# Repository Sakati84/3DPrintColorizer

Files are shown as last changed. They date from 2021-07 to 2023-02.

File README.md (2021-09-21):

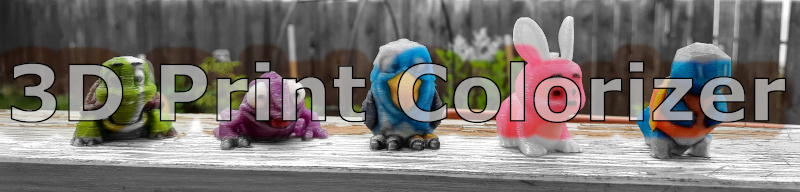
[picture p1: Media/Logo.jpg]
  

**3D Print Colorizer** is a combination of 3D printed parts and a [Cura](https://ultimaker.com/de/software/ultimaker-cura) plugin which allows anyone with an Ender 3 or BLTouch-compatible printer (no CoreXY for now) to produce multi colored models. Have a look at some results:

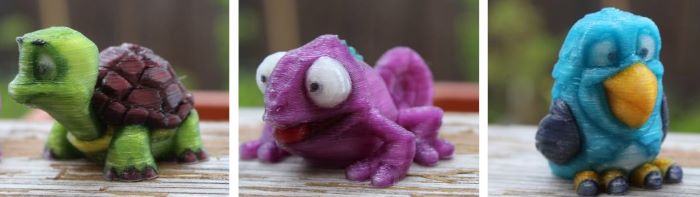
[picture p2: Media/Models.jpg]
  

## Release Notes
- **2021-08-06** Fixed issue with some T-Commands still being in the G-Code as reported by Teaching Tech.
- **2021-08-05** Added big compatibility update. Added parts to mount to nearly any BLTouch-compatible Printer (no CoreXY for now).

## How it works
3D Print Colorizer uses Sharpie or Sharpie-like permanent markers to directly paint on the layers of a 3D print. After a layer is finished printing normally a pen holder, which is mounted to the print head, is used to fetch pens from a special pen rack mounted to the top part of the printer. Normal printing and painting is used alternately to produce a final colored model.

To coordinate the process a special [Cura](https://ultimaker.com/de/software/ultimaker-cura) plugin is used to  add the painting G-Code. After installing the plugin you need to enter some calibration values and afterwards models sliced for an Multi Extrusion printer can be printed on an Ender 3 with full color support.

  
*[YouTube link](https://youtu.be/2vPkmsyEDaQ)*

## Installation
You can watch this video for a quick overview of the setup process:  
IMAGE ALT TEXT HERE (https://www.youtube.com/watch?v=U__G75EYIEQ)  
*[YouTube link](https://youtu.be/2vPkmsyEDaQ)*

Detailed installation instruction are given in the [Wiki](https://github.com/Sakati84/3DPrintColorizer/wiki/1-Hardware-Setup). Please follow each step to complete the installation and get ready for mutli color printing.

> **PLEASE don´t forget to:**  
> + Use **transparent** filament. **No white** filament!
> + Tune your Z-Axis.
> + Use the provided Cura profile as a starting point and **don´t** increase the speeds before you know what you are doing. 

[1. Hardware Setup](https://github.com/Sakati84/3DPrintColorizer/wiki/1-Hardware-Setup)

[2. Materials needed](https://github.com/Sakati84/3DPrintColorizer/wiki/2-Materials)

[3. Calibration](https://github.com/Sakati84/3DPrintColorizer/wiki/3-Calibration)

[4. Software Setup](https://github.com/Sakati84/3DPrintColorizer/wiki/4-Software-Setup)

[5. Printing](https://github.com/Sakati84/3DPrintColorizer/wiki/5-Printing)

---
If you want you can:

<a href="https://www.buymeacoffee.com/sakati" target="_blank">Buy Me A Coffee</a>

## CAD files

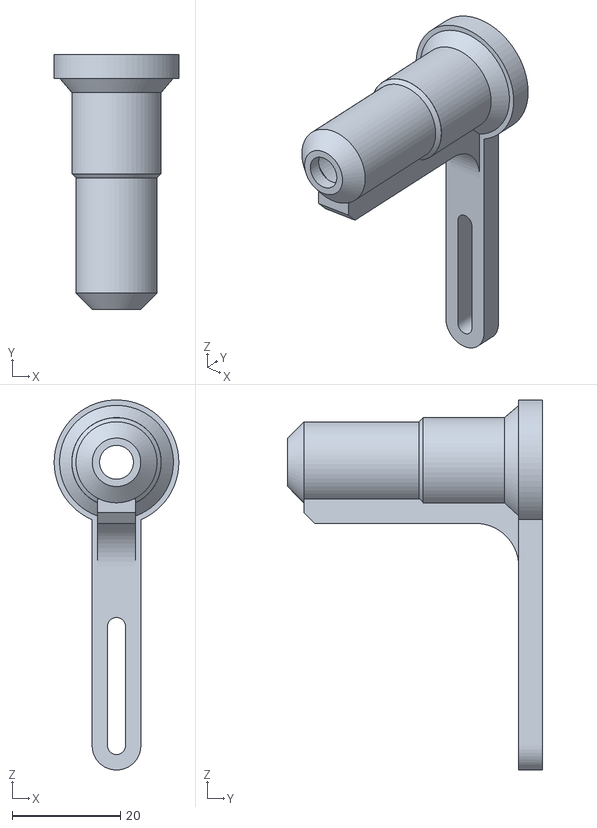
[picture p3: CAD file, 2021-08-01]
Hardware/BLTouchPenHolder/PenHolder_Long+1.stl
23.0 x 47.0 x 68.2

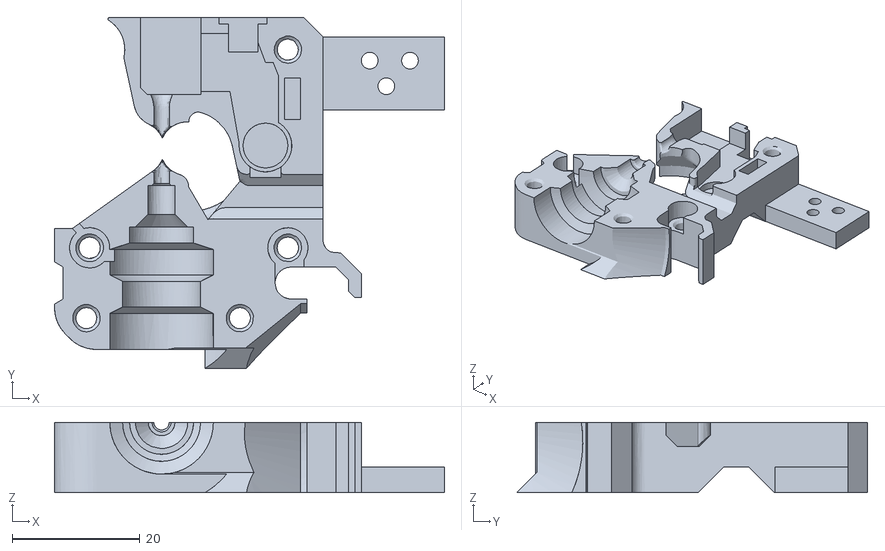
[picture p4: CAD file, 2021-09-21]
Hardware/PrusaMK3S/colorizer-extruder-attachment.stl
61.0 x 54.9 x 11.0

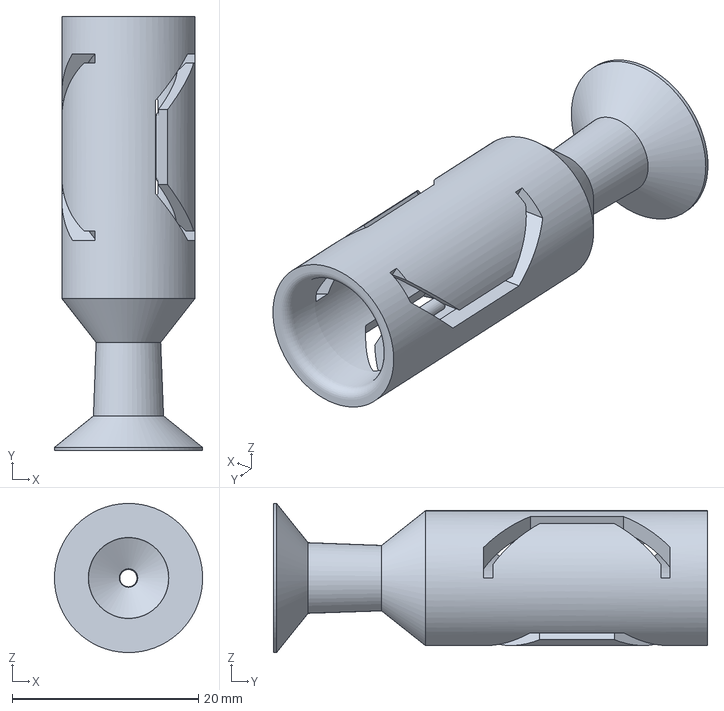
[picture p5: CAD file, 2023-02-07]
Hardware/UFSharpieCap.3mf
15.9 x 46.6 x 16.0 mm

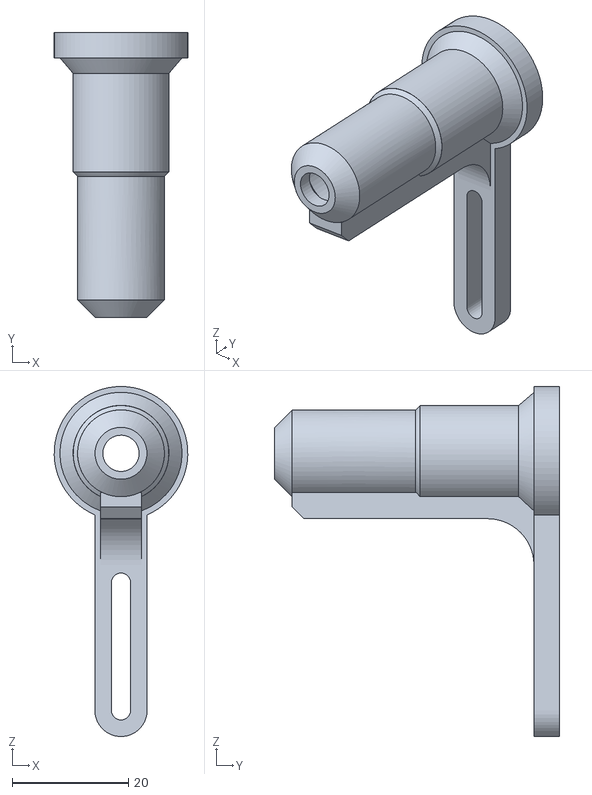
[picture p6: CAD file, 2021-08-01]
Hardware/BLTouchPenHolder/PenHolder_Short+3.stl
23.0 x 49.0 x 60.2

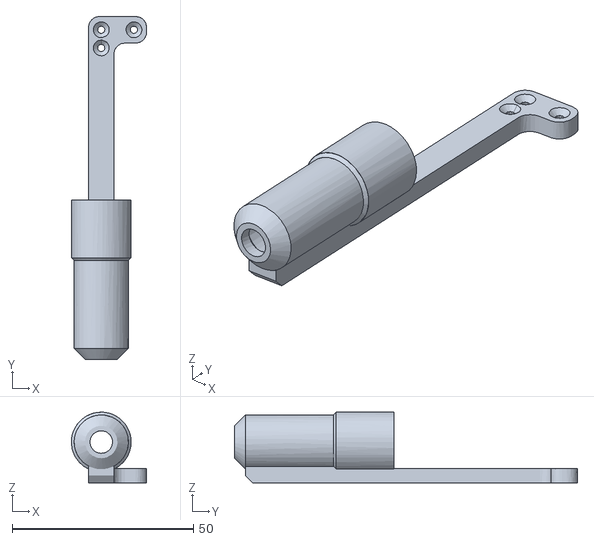
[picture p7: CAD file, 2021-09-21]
Hardware/PrusaMK3S/Colorizer MK3S holder.stl
20.7 x 94.5 x 19.5

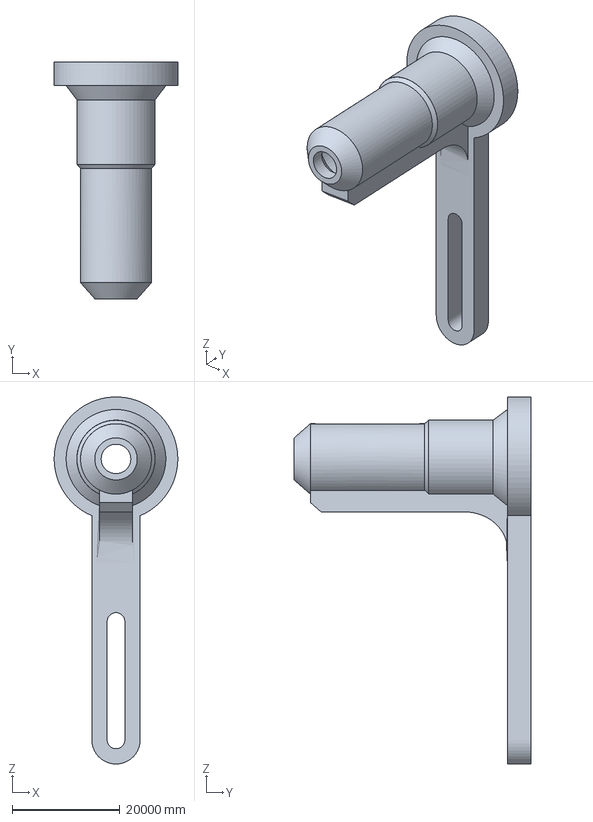
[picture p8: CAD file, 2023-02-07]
Hardware/UFSharpieHolderLong-2.3mf
22997.4 x 44000.0 x 68224.1 mm

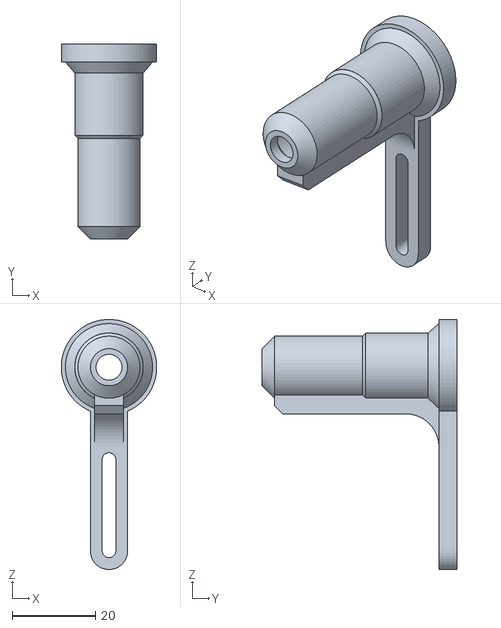
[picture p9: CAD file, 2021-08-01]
Hardware/BLTouchPenHolder/PenHolder_Short+1.stl
23.0 x 47.0 x 60.2

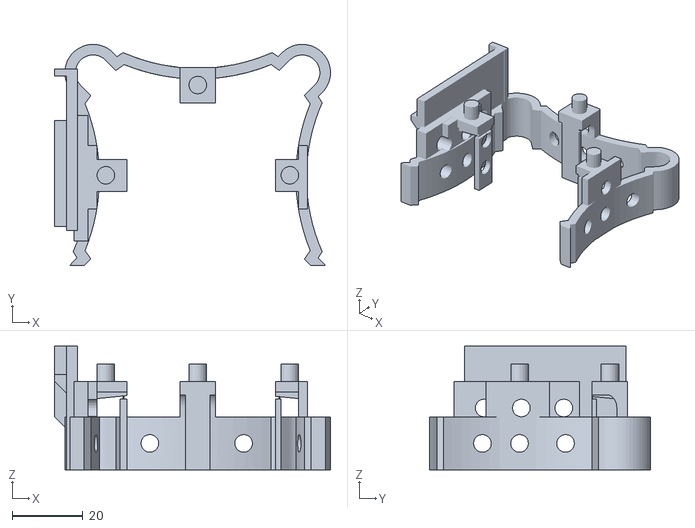
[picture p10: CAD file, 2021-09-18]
Hardware/PenHolder Ender3v2_Cyrus_Sanii (ClipOn).stl
78.0 x 62.5 x 35.0

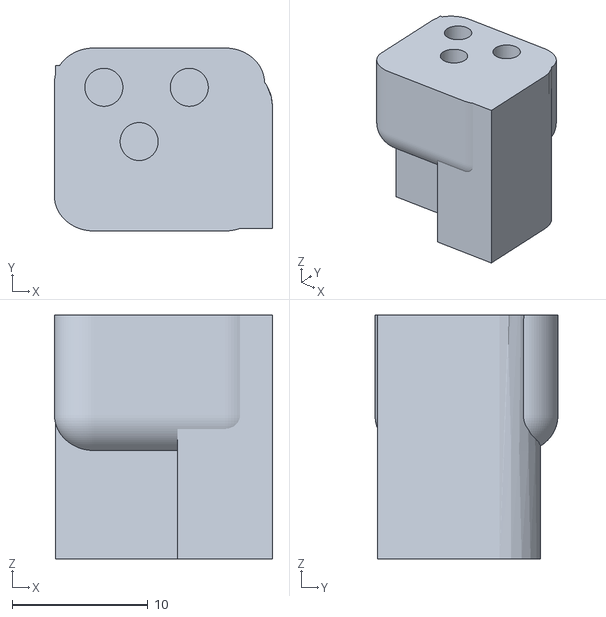
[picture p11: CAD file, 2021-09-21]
Hardware/PrusaMK3S/colorizer-extender.stl
16.1 x 13.5 x 18.0

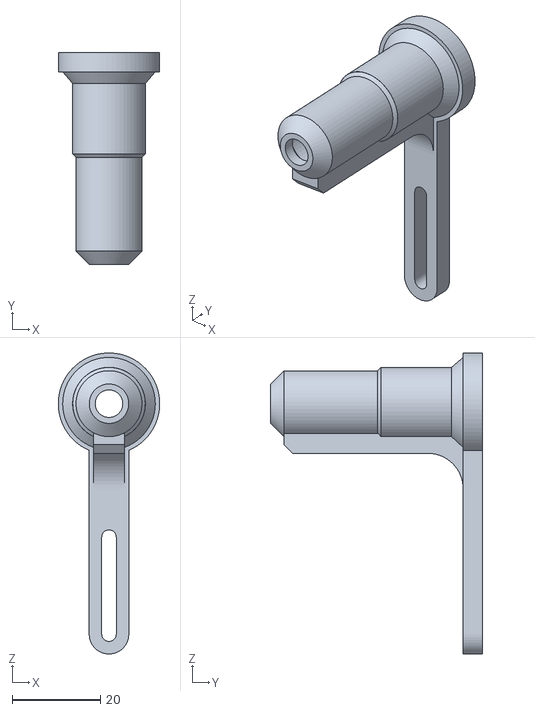
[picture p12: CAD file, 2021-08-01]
Hardware/BLTouchPenHolder/PenHolder_Long+2.stl
23.0 x 48.0 x 68.2

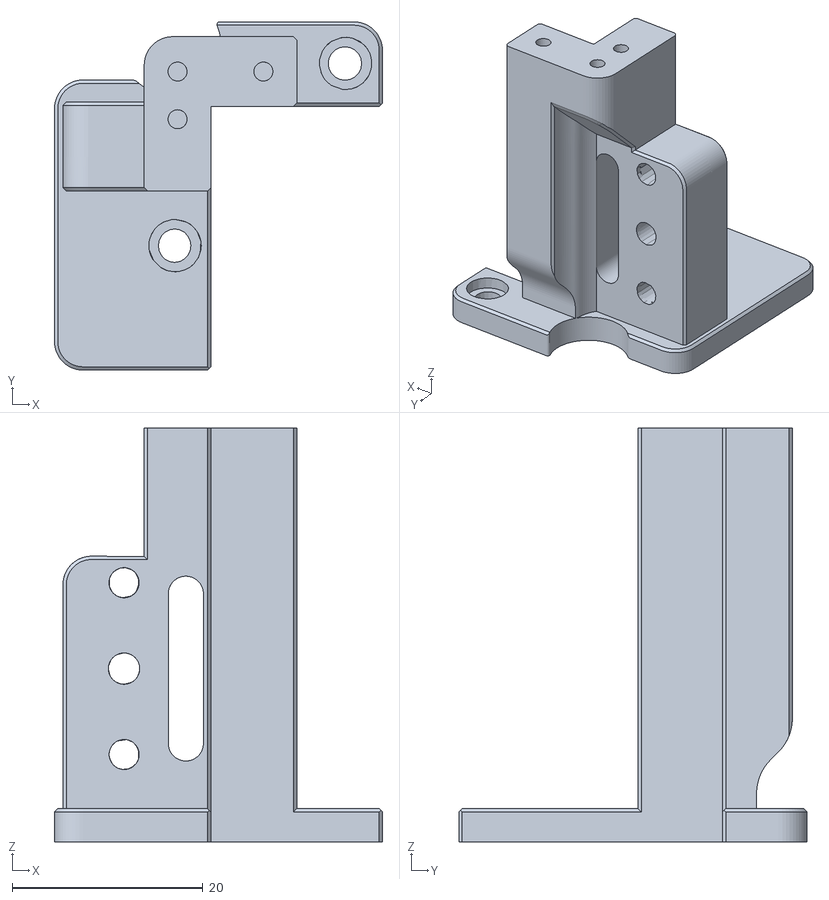
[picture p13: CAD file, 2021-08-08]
Hardware/PenHolderArm_Ender3v1_IntegratedBLTouch.stl
34.4 x 36.5 x 43.4

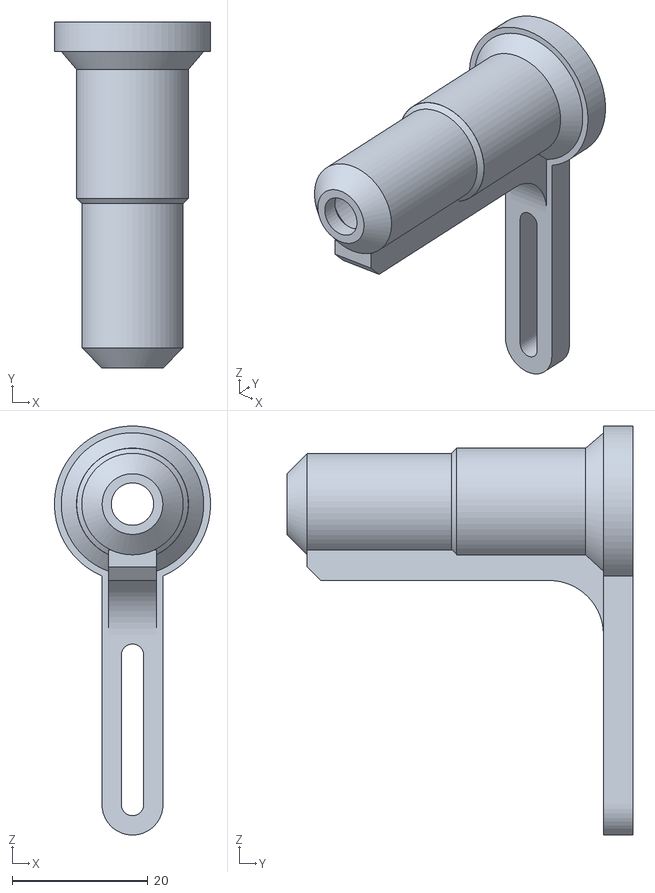
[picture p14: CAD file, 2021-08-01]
Hardware/BLTouchPenHolder/PenHolder_Short+5.stl
23.0 x 51.0 x 60.2

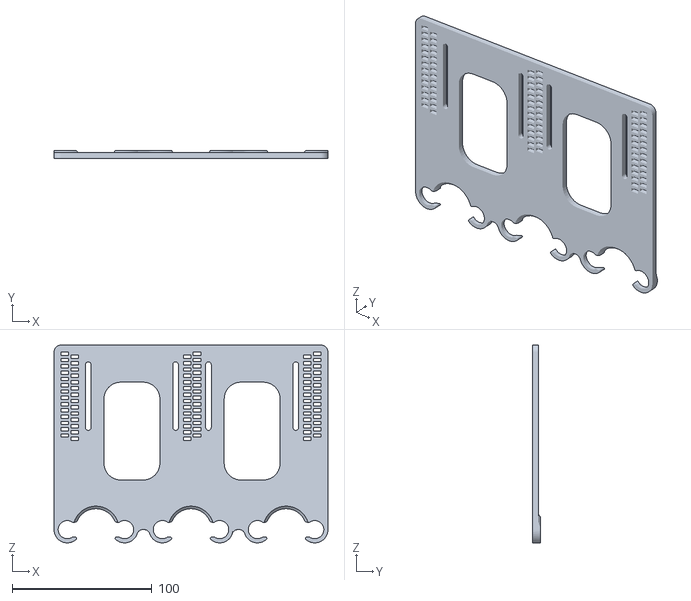
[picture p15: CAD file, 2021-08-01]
Hardware/PenRack_x6.stl
196.0 x 5.40 x 141.5

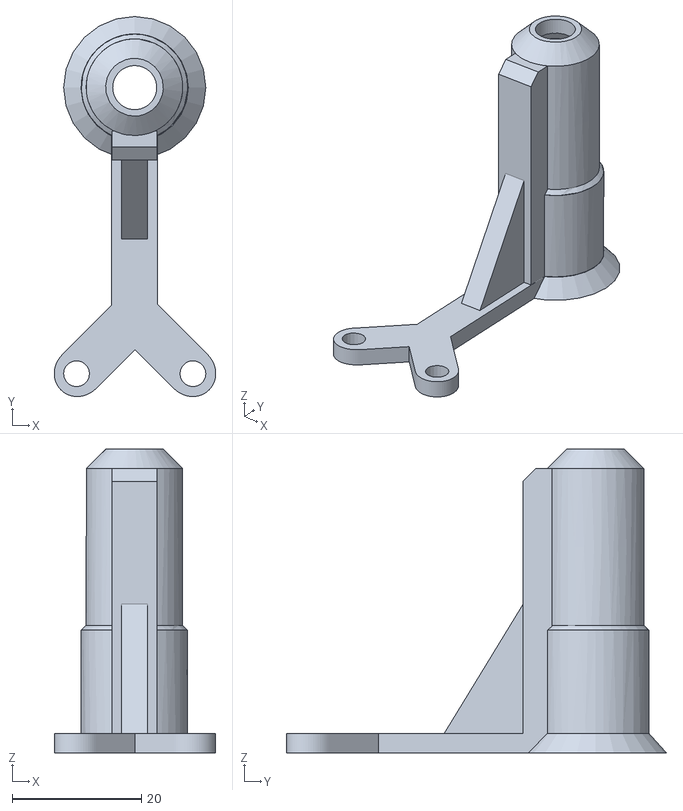
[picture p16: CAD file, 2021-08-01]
Hardware/BLTouchPenHolder/PenHolder_BLTouch_horizontalByZippitybamba.stl
25.0 x 58.8 x 47.0

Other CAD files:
Hardware/PenHolderArm_Ender3v2_byMolesza.stl
Hardware/BLTouchPenHolder/PenHolder_Long+4.stl
Hardware/PenHolder_Sharpie.stl
Hardware/BLTouchPenHolder/PenHolder_Long+3.stl
Hardware/BLTouchPenHolder/PenHolder_Long+5.stl
Hardware/BLTouchPenHolder/PenHolder_Long-1.stl
Hardware/BLTouchPenHolder/PenHolder_Long-2.stl
Hardware/BLTouchPenHolder/PenHolder_Long-3.stl
Hardware/BLTouchPenHolder/PenHolder_Long.stl
Hardware/BLTouchPenHolder/PenHolder_Short+2.stl
Hardware/BLTouchPenHolder/PenHolder_Short+4.stl
Hardware/BLTouchPenHolder/PenHolder_Short-1.stl
Hardware/BLTouchPenHolder/PenHolder_Short-2.stl
Hardware/BLTouchPenHolder/PenHolder_Short-3.stl
Hardware/BLTouchPenHolder/PenHolder_Short.stl
Hardware/PenCap.stl
Hardware/PenHolderArm_Ender3v1.stl
Hardware/PenHolder_Amazon_ShuttleArt(_Sharpie).stl

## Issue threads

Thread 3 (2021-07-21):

No support for G2/G3 codes.

FlyMyPG, 2021-07-21:
I use ArcWelder, which detects arcs made from a sequence of G0/G1 codes and converts the entire sequence to a single G2/G3 code.  It makes highly-detailed STLs print faster and better, especially on 8-bit controllers.

I'm planning to adapt the project to the Sidewinder X1 v4, so I may code this myself if you don't beat me to it!

FlyMyPG, 2021-07-21:
Doh!  I could just ensure ArcWelder runs **_after_** PenColorizer.

Please close this issue if you agree.

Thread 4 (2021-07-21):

Feature request: support

jmding8, 2021-07-21:
Would it be possible to extend the plugin to support using the Sharpie as a release agent for support structures?

Check out this video, which shows how you can use Sharpie as a release agent to enable printing over 100% density support structures with zero Z-gap, and still have the support structure break away from the part easily.
https://www.youtube.com/watch?v=lcOcetpHhTU&ab_channel=ChristianGalles

I've tried it with PLA and ABS and it works amazingly well. The one major downside is either needing to apply the Sharpie manually, or being stuck using a non-zero Z-gap, since none of the open slicer engines support zero-thickness layers. Your system would be perfect for an application like this!

Sakati84, 2021-07-22:
Very first test print
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

jmding8, 2021-07-22:
amazing!

Sakati84, 2021-07-26:
Some other results. This print has no gap between the print and the support interface and was easy to remove.

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

jmding8, 2021-07-26:
looks like the automated system works really well! This is all using the current plugin code? Next step: get this in the hands of a prominent influencer to popularize the technique and the use of the plugin?

Sakati84, 2021-07-26:
@jmding8 i tried to pitch it to makers muse and make anything some weeks ago but got no reply.

Sakati84, 2021-07-26:
@jmding8 the Support Mode isn‘t on GitHub yet. I want to change some stuff before I upload it

ssilverm, 2021-07-27:
Going to be printing this and showing it off at Maker Faire Orlando!

Sakati84, 2021-07-27:
@ssilverm thats really cool. Would be nice if you could post some pictures.

jmding8, 2021-07-27:
I'll poke Tom and Stefan, I'm sure one of them will jump on it

Sakati84, 2021-07-27:
I made a [branch](https://github.com/Sakati84/3DPrintColorizer/tree/supportRelease )for this feature. It´s still very much WIP. I only tested it for supporting horizontal overhangs right now. In the branch you have an updated plugin. In the settings panel you can switch the mode to "support removal". I also suggest you use the new support removal profile a uploaded to the software folder. The new TestModels folder contains my test model from before. If you want to do your own profile you should increase the wall & top speed to a normal/fast level (normally they should be reduced for the colorization profile).

dr3y, 2021-08-16:
but what if i want to print support and also a multicolor model at the same time?

Great addon idea btw

Sakati84, 2021-08-16:
I don't think this would work very well. One would probably destroy parts of the model when removing the support because of the reduced layer adhesion in the Colorado parts

dr3y, 2021-08-16:
well currently i am using a colored model with uncolored supports and it is extremely hard to remove them. i think this would at least make my life easier if the supports were colored also and therefore had a weaker layer adhesion, just like the model. Combined with other support weakening options like decreased flow rate and fill density i could actually print colored protein models quite well :)

Sparrowhawk120, 2021-08-19:
I am trying to use the support removal branch of the repo and I made one or two modifications to the profile but when I try the test model the underside surface ends up looking like this:
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

I watched it while printing and the layer above the support interface didn't stick at all to the sharpie layer while going down (which is what we want of course but not while it's printing!). So I ended up with a bunch of balled up filament on that layer, resulting in the bad underside finish. Since yours clearly worked out @Sakati84 is there anything I did wrong?

Sparrowhawk120, 2021-08-19:
Also, I noticed that there is a z-axis hop every time it moves over the support material even though z-hop is disabled in cura..

jmding8, 2021-08-19:
Guessing that your profile isn't optimized for fully dense supports?
support z distance = 0.0mm
enable support interface = true
support interface density = 90% to 100%

If that doesn't fix it, use the plugin referenced in this conversation to export your settings. Paste them here, and I can take a look

Sparrowhawk120, 2021-08-19:
@jmding8 I do have those settings, yes. 0.0mm, 100% concentric roof interface. I don't see the plugin referenced in this conversation could you tell me what it is?

jmding8, 2021-08-19:
Apologies, I meant to paste this link, but I guess I forgot

https://community.ultimaker.com/topic/35866-include-cura-settings-as-comment-in-gcode-file/

Sparrowhawk120, 2021-08-19:
https://pastebin.com/qMk07FxQ

Here's a pastebin, is this what you were looking for?

Sakati84, 2021-08-19:
>
>
> Also, I noticed that there is a z-axis hop every time it moves over the support material even though z-hop is disabled in cura..

That is one of the WIP things in this branch ;-)

Sakati84, 2021-08-19:
Can you post your g-code? What modifications did you make?

Sparrowhawk120, 2021-08-19:
[SupportTest1.zip](https://github.com/Sakati84/3DPrintColorizer/files/7015762/SupportTest1.zip)
Too big for a pastebin so I zipped it up
The major modification I made was to increase the speed because the printer can handle it, but even when it was slowed down to 33% for the layer above the sharpie it still didn't adhere properly :( . The filament just got dragged around and only some of it stuck down enough to finish the print

Sparrowhawk120, 2021-08-19:
Intriguingly using the default profile in the folder yields much better results, so I am going to do some testing on what parameters are messing up the print and report back in a few days :)

Dudedud, 2022-07-18:
Hello Hello! I'm wondering if this project is still being worked on. If so, have there been any updates to this request?

Sparrowhawk120, 2022-08-09:
> Hello Hello! I'm wondering if this project is still being worked on. If so, have there been any updates to this request?

It's been 11 months, I doubt its ever going to reach its full potential sadly.

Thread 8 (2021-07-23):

Direct Drive extruder

Vantiveman, 2021-07-23:
I have a CR-10 that I have converted to direct drive (Micro-Swiss). The instructions for this plugin said it needed a larger retraction, but with direct drive where retraction is set to around 1.5mm a larger retraction is likely to cause a jam.
Is there a workaround or modification that would work with a direct drive converted Ender or CR-10?
Thanks,
Al

Sakati84, 2021-07-23:
Hey, the larger retraction is only needed for a bowden extruder because of the pressure in the bowden tube. I think for a direct extruder you can set it to zero or a small value. The worst thing that could happen is a little amount of oozing. In this case you can try out a ooze or draft shield. Please share your experience / parts when possible.

Vantiveman, 2021-07-23:
Cool! Thank for the reply.

Seems like a nice thing to try as I keep switching back and forth between wanting dual extrusion or not. I’ll get printing over the weekend and order some sharpies. Might need a slight mod to the pen holder, as I have my reel holder mounter on the top bar of my CR-10.

If I get it installed and working I’ll post the experience and anything to look out for in a direct drive setting.

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

GrahamPrattWyalong, 2021-08-12:
Hi there, I have the same concerns with a DD extruder!

I have set it all up on the ender3.

all positions work fine and dandy except the retraction!

the retraction even if set to 0.0 and disabling retraction in the extruders in Cura themselves still rolls back the extruder by more than 75mm.. this is the amount of retraction needed to clear the drive cog!.

When I push the filament back in it oozes so much filament that it then causes x and y jamming!

I have looked in the script and in theory it inserts 0 for the retraction moves as best I understand it!

Any insight would be greatly appreciated!

BTW I have modified the STL for the holder and pen caps to allow for the DD (I manually cut the holder chunk so can't really provide the STL mods for that one!.

Regards.

Graham.

GrahamPrattWyalong, 2021-08-13:
OK I have run a bucket load of tests..

The only way this works for my DD on Ender3 without spitting anything out, Oozing or stringing is to....

Turn OFF retro in ALL pen extruders.
Turn ON retraction for Extruder 1 and set to normal anti stringing level
Ignore the Extra Retraction setting.
Rem out all inserted retraction and feed lines that show G1 F1500 E(- or nothing for return of filament)(Value set in box)
For me however modifying the script to still insert the lines but put a rem (;) in the output so they are ignored is best simple bet for now!

Hope this research helps others with Direct Drive.
I shall post the extended pen caps stiles to thingiverse as a remixed!

Regards.

Graham.

Sakati84, 2021-08-16:
Hi, thnaks for all the research! Can you post or do a pull request for you profile/script? I would like to have a direct extrusion Check box in the plugin.

GrahamPrattWyalong, 2021-08-17:
> Hi, thanks for all the research! Can you post or do a pull request for you profile/script? I would like to have a direct extrusion Check box in the plugin.

No Worries. here is a .2mm profile that works BUT..... there is a nasty extrusion occasionally that I have not nailed down yet! I am not sure why it occurs I am printing a more accurate pen holder before I test to try and find the bit of nasty code!

as regards your modified script, I simply inserted the rem where you add the extrusion movement + and - ergo "G1 F1500 E-" became ";G1 F1500 E-" and "G1 F1500 E"  became ";G1 F1500 E" as I am only using the DD machine.

I am happy to test your modified script if you want to send it to me!

oh and the .txt is a bodgy it is a .curaprofile file but the upload would not allow it in this forum so change it back when you get it!

[DD Colorizer Retract profile.txt](https://github.com/Sakati84/3DPrintColorizer/files/6996339/DD.Colorizer.Retract.profile.txt)

Cheers
G.

kohend, 2021-09-09:
I set it to 2 mm in my Prusa MK3S+, seems good, didn't get oozing despite using a very oozing filament.

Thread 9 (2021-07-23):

PrusaSlicer support?

Sonosus, 2021-07-23:
I don't know if it's possible, but is porting this to PrusaSlicer viable? My Ender has really bad layer shifts with Cura. I'm not a developer so have no idea how difficult it would be, feel free to close this!
Many thanks

Sakati84, 2021-07-23:
It‘s possible but to be honest I would like to wait for some results from the current Cura plugin. But if enough people want a Slicer Plugin I will definitely do it.

msazanov, 2021-07-26:
+1 PrushaSlicer (SuperSlicer)

Sonosus, 2021-07-30:
Ok, no bother. Off printing parts now, will give Cura another go.

adelyser, 2021-08-11:
+1 for PrusaSlicer

Toxyped, 2021-08-13:
+1

TechnomacherRyu, 2022-03-04:
+1 for PrusaSlicer

Dashrendar2507, 2022-04-04:
@Sakati84 Hi! Is this something you are still considering? I'm wanting to use this in SuperSlicer and wanted to know what were your plans (if any) before I start designing mounts for my machine. Thanks!

Nathan22211, 2022-04-17:
There's an advantage to using Prusa slicer/super slicer for this. You can color parts of the model for different extruders. I don't think you can do that in Cura

Niyazi-Oezel, 2022-12-19:
+1 for PrusaSlicer. I love Prusaslicer. Before I spent too much time with Cura, but for third party printers like the Ender 3 Prusaslicer just plug and play.

dbech, 2023-01-23:
I've not tried the project yet but I could imagine my way through what would needed to get this working with prusaslicer.
I'll take a crack at it later in the year.

scanlight, 2023-03-16:
would be awesome to have this function un prusa. left cura years ago, never looked back haha
+1

LouisLe18, 2023-03-17:
YES +1 Prusaslicer

1412kauti, 2023-03-25:
+1 Prusaslicer

luemonkey123, 2023-05-09:
+1 Prusaslicer

Nathan22211, 2023-05-25:
for anyone needing prusa slicer support try this: https://github.com/krisrok/3DPrintColorizer/blob/feature/prusaslicer-compatibility/Software/PenColorizer.py seems to just recreate the Script class Cura uses but I haven't run a dry run with it yet. @Sakati84 this might be something to try perhaps

doggohusk, 2023-08-25:
+1 for PrusaSlicer

doggohusk, 2023-09-03:
i tried using that in prusaslicer and could not get it to workwhen i try to export it it just gives errors waying this class doesnt exist also theres no custom parameters like first pen position or pen offset so i cant even configure that

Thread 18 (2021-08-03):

Outer wall only colorizing

ssilverm, 2021-08-03:
Would there be a way to only have the PenColorizer plugin generate gcode that colors the outer edges of the models?

I had an issue printing a dual extrusion Pikachu where because the sharpie colored in the whole tail layer the print separated.

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

Pineapplecake, 2021-08-03:
The setting `Infill > Infill Extruder` in CURA can be used to print all infill with Extruder 1, i.e. without colorizing.

Sakati84, 2021-08-03:
Unfortunatly no. You could set the top/bottom Extruder to 1 but than you would have no color there. To solve this you could: reduce the top/bottom speed or print it larger or change the model so it interlocks at this position

ssilverm, 2021-08-06:
Thanks!

Closed 2021-08-16.

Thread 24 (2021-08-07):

MARLIN BUGFIX2.0.X

scootr1975, 2021-08-07:
I followed instructions and used the sample print. When I went to print it did not recognize the extruders. I use octoprint with my Ender 3 Pro. I have done several upgrades to the unit. I have the Creality 4.2.7 32bit board with direct drive extrusion. I have dual Z-axis. I have included some pictures Please help
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

Sakati84, 2021-08-07:
Hm.. for some reasons he doesn’t like the T0 command. This should normally refer to your first and only extruder. Does it work directly via USB or SD-Card?

stldenise, 2021-08-16:
I'm setting up an Ender 3 Pro also. I'm not a tech geek, so ignore if you did this: did you set up a new printer profile in OctoPrint with 7 nozzles? I was getting a similar error and they vanished when I set up a "new" printer.

scootr1975, 2021-08-17:
No I did not. Thank you for the information. Did you check the share button
when you added the extra extruders or did you put in the offsets there.

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

stldenise, 2021-08-17:
You know, it was late when I did that...didn't even see it! So, no I did not click shared nozzle or anything else.

scootr1975, 2021-08-17:
Haha, thanks!

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

scootr1975, 2021-08-19:
Awesome, thanks!

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

Closed 2021-08-19.

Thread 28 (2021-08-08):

Improvement Idea: Hang sharpies from the tip

ianespana, 2021-08-08:
First things first, I have checked out this system and I am quite impressed by how simple it is!

However there is one flaw with it: Because of the way the sharpies hang from the back with the end cap you effectively remove a chunk of printing space in Z. So, what about changing the way sharpies are held?
Instead of hanging them from the end it'd be better to hang them from the front, similar to adding a front cap to the sharpie. This would not only allow you to reclaim a lot of space in Z, but it would also allow you to use different length sharpies.
It'd also mean you have a more secure way of holding the sharpie as it's own weight would be pushing it into the cap.

Depending on the mounting solution it might even be capable of mounting different types of markers while keeping the pen arm and the rack the same.

Has this been considered or tried before? What do you think some drawbacks with this system might be?

Sakati84, 2021-08-09:
Hi, thanks for your suggestion. I'm not 100% sure I understood it right. From what I understood it seems like this would compress the bowden cable to much.. Could you perhaps provide a very basic drawing?

ianespana, 2021-08-09:
Sure thing!
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

On the left is the current configuration where the end cap is what holds the pen in place
On the right is my proposed change, where the cap goes on the front of the pen and reduces the length that's hanging down

RyushoYosei, 2021-08-10:
The issue I see with this, is you would need to have the holder lower, or a Z axis that could actually raise high enough to get to it.

Sakati84, 2021-08-10:
I see some problems with bowden extruders. I will leave this open as an idea. I'm working on a new holder/rack design which should solve a lot of this problems. If it doesn't turn out to work I will revisit this idea.

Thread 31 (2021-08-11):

Missing source code

mousethief, 2021-08-11:
I notice that none of the .stl object code files for the 3D printed parts have any corresponding source code files anywhere on the repo. How are people even making contributions?

ShadowBr0ther, 2021-08-11:
Those files are located unter the folder "Hardware"...

mousethief, 2021-08-11:
There are only object (stl) files in the directory 'Hardware'.

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

csanii123, 2021-08-21:
If you go 1 directory up you will find a Software directory. In there is the Python code that does the post processing of the gcode to do the coloring.

kohend, 2021-09-09:
I just edited the STLs, since the calibration is based on the actual hardware setup, so dimension differences in mount and caps do not seem to matter as long as you're calibrated.

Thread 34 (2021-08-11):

I can't turn on Infill first

Beanman122, 2021-08-11:
I was thinking of how to make the quality better and I thought that it would help to turn on Infill before walls. Unfortunately, It turns out that you can't turn that on because the infill is using extruder 1 and the walls are not. If you turn the extruder settings for the infill to "not overridden" you are able to make this change. I don't know if this is possible but I was wondering if that setting would help and if there is a way that you could turn it on.

Sakati84, 2021-08-11:
You can Set the infill Extruder to not overwritten. Infill is never colored. It's filtered out by the plugin.

Beanman122, 2021-08-11:
oh, cool. Thanks so much

Closed 2021-08-11.

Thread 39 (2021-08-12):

minor bug... M900 for linear advance on each tool.

jmerc77, 2021-08-12:
M900 for linear advance on each tool. should be only one tool.
what I have in gcode:

...
M900 K0.130000 T3 ;added by LinearAdvanceSettingPlugin
M900 K0.130000 T0 ;added by LinearAdvanceSettingPlugin
M900 K0.130000 T2 ;added by LinearAdvanceSettingPlugin
M900 K0.130000 T1 ;added by LinearAdvanceSettingPlugin
M900 K0.130000 T4 ;added by LinearAdvanceSettingPlugin
...

should be:

...
M900 K0.130000 ;added by LinearAdvanceSettingPlugin
...

Sakati84, 2021-08-16:
I don´t really see the problem here - this was generated by another plugin. How should this be fixed in the colorizer plugin?

jmerc77, 2021-08-16:
the T parameters should not be there. mainly for consistency. even better would be to have only one of those left in but without the T parameter. same should be filtered for other tool specific G and M codes. even though this may not happen to everyone it is still a good idea to cover all scenarios.

Sakati84, 2021-08-16:
What does this look like with the LinearAdvanceSettingPlugin deactivated?

jmerc77, 2021-08-16:
the developer of that plugin did not provide a disable box. I can only uninstall it or set values to 0. without the plugin there would not be such lines. however, I use the plugin to help with making my line width more consistent and uninstalling it would likely hurt my print quality. setting to 0 has no effect on the existence of these lines. also the plugin is a market place plugin that loads on startup. therefore in a way not a post processing plugin.
also not quite sure if it is fixable as I don't know which runs first. hopefully the linear advance plugin (and others like it) run first.

Sakati84, 2021-08-19:
Sorry but I won´t & can´t fix other plugins.

Closed 2021-08-19.

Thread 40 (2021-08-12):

first layer z offset and filament output

eyaltheking3, 2021-08-12:
Hello I have a problem when in my first layer with the different exdurder my first layer sucks, the nozzle is too far away and changing the z offset won't help, also there is not enough filament in the first layer and its messy please help

Sakati84, 2021-08-16:
Can you post your G-Code normally the plugin doesn´t modify the normal printing codes. So I don´t really know how it could have affected your Z-Offset.

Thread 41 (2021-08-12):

Need Test Routines and a little feedback

ridan, 2021-08-12:
This is such a cool project. There are a couple of things that need to be included in the documentation to speed up the process of installing, tuning and getting started.

**_Testing routines_**
Firstly there needs to be a quicker way of testing without starting a print. I wonder if this can be a set of scripts that we load next to the PenColorizer.py
these scripts can do a few things
1) pick pen X, where X is one of the extruders. This test will allow us to see if the printer can pick the pen in the right direction or not and find out if any of them are misaligned
2) Draw a circle on X layer, here X is the layer height. This will have a checkbox called "assume pen loaded". This will allow us to see if z is properly calibrated for the printer. make a quick circle or some shape at a certain layer. With the checkbox we can combine a test of picking up a pen and testing the Z for coloring

Also if there were a few instructions on what kind of pen holder arm is needed. I just realized it is best to have the pen holder be much further out from print head. If not then it always hit the other pends when going up. I designed my own because I have a satsana fan shroud and at one point it seems like the pen was going to get stuck in the fans and ruin it. Most of the modders that use this will have custom fan shrouds with exposed fan so be careful.

apart from that it's a great project

Sakati84, 2021-08-16:
Good ideas. I still have some other stuff to do but after this I will try to add this. As for the position of the arm: I recently updated the Wiki for the BLTouch holders and there is a description on where to put the arm. I know one other person who had this problem before.

csanii123, 2021-09-04:
Basic pen test files for #1 that you mentioned.
[Pen_tests.zip](https://github.com/Sakati84/3DPrintColorizer/files/7110133/Pen_tests.zip)

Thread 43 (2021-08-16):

Cant Print Second Layer

Shynka, 2021-08-16:
I modified my GEEETECH A10M 3D Printer.  removed one of the extruders repositioned the other one with double sized tape on the  power supply. Need to reposition the fan. But after doing so much testing and not enough screws I hot glued everything together, leaving me with 4 colors total...

I've probably tried for a full day. But for the life of me I can not get the second layer to stick the Cura.
I've leveled the bed so many times.
I have normal prints working with Repetier and Easyprint Lite Release with the profiles provided by the Company that sells the printer.

So anyone know how to Either change the profile to another software or how to get Cura to work.

Sakati84, 2021-08-16:
Did you use the provided Profile?

Shynka, 2021-08-16:
> Did you use the provided Profile?

I tried the provided one. Looking into the code and and comparing with the that comes with the printer.
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

Sakati84, 2021-08-19:
What is your print speeds for the top/bottom layers & walls?

Shynka, 2021-08-20:
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
Like it gets the first layer great. then the second is not sticking

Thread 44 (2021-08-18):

Can't Reach Pen #7

JohnSpoAA, 2021-08-18:
I ran a test print to ensure all pens could be reached on a standard print, Pen #1 aligns perfectly, but there is more and more of a gap the farther down the rack the hotend goes. Pen #7 Doesn't align at all with the pen holder.

My steps/mm are calibrated and the size is correct, as there should be what seems like 40mm between the pen rack holes.

Could I suggest some sort of averaging system?

Take the first and last hole measurements and average them out to equal 7 equally separate holes?

I'm really grasping at straws here, it seems like I can't find this issue anywhere else.

Thank you in advance!

HunterG6700, 2021-08-23:
Try to loosen up the screw at 7 and adjusting it a little until it works. That's what I did and mine seems to work so far. Also maybe make your first position x 1mm larger

ivanmailru, 2021-09-03:
Same problem here. I have Ender 3V1 with no upgrades and stock firmware. The slicer used is Cura 4.10

csanii123, 2021-09-04:
Just eyeballing the centers for the pens using Cura and I see about 42mm for 2-3, 4-5, and 6-7 and about 27mm for 3-4 and 5-6.

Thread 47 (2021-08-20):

Putting a marker away and picking up the next one.

isaacBullinger, 2021-08-20:
To save time later on in the print, when the holder goes up to put away a marker, it picks up the next one needed. It would need to start doing it at a higher layer, otherwise it would draw on the bed.

Sparrowhawk120, 2021-08-21:
I don't think that would work though. For the same reason it would draw on the bed with too-low layer heights, the marker would smack into the print if it's bigger than the size of the print head.

Sakati84, 2021-08-21:
I also think it would knock over the print.

Closed 2021-08-21.

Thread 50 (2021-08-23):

Feature Request

HunterG6700, 2021-08-23:
I thought this would be a nice addition. You know how you can change the colors of the materials you use in Cura and how you can assign each extruder a different color. Well I thought it would be a good idea to have a message at the beginning of the print that tells you where to put the sharpies then it says press button to continue. Once you press the button the printer heats up and starts the print.

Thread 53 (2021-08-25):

Prusa i3 support

kohend, 2021-08-25:
Hi,
I wondered how complex it'll be to add support for the Prusa i3 MK3S printer, what needs to change apart from the head pen mount and the top mount? Will the calibration be able to handle the differences between the printers?
I may be able to do most/all of the work, but I want to get a better understanding of the needed effort.

Sakati84, 2021-08-25:
You should be able to mount it with the New bltouch mounts and zip tie rack. Have a look at the Wiki!

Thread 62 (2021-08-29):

My nozzle is digging on my print

CjSd1, 2021-08-29:
The first layers will be laid fine but later on it will be pushing against the print and flexing the springs of my bed, and grind against the print.

Sakati84, 2021-09-07:
Pls send me your GCode so I can make sure it is a Software and not a Hardware porblem.

MXZZ, 2021-09-09:
I have the same issue, seem that using the ender3 pro and the "Custom FDM Profile" the Z axis appear to be reversed
here is my gcode
[CFFFP_DualStrusion-spiralCylinder_m1.zip](https://github.com/Sakati84/3DPrintColorizer/files/7135569/CFFFP_DualStrusion-spiralCylinder_m1.zip)

JMVS, 2021-09-13:
I'm having the same problem on an Ender 3 v2. I have to manually increase by 0.20 the Z Offset for every new layer to prevent crashing over printer parts. Here's the code:
[CFFFP_Tolve_Deco_Llavero_(Italia).zip](https://github.com/Sakati84/3DPrintColorizer/files/7150550/CFFFP_Tolve_Deco_Llavero_.Italia.zip)

MXZZ, 2021-09-13:
how do you increase the z offest ? you replace the gcode lines by hand or you have a script?

MXZZ, 2021-09-13:
could it be that our Z axis is wired wrongly?

I noticed that im able to print normally without any colour so i can exclude the profile/printer i'm trying to identify the issue in the python script ..

JMVS, 2021-09-13:
>
>
> how do you increase the z offest ? you replace the gcode lines by hand or you have a script?

In the Tune menu, whilst the printer is printing.

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

The printer is doing just fine with regular prints and the finish is far superior in those cases. I've only starting using 3DColorizer  recently and this was my second colored print after the first test (which did something similar but wasn't as noticiable as it was lower -less layers-).

Probably something to do with the Python script and maybe a combination with the printer (Ender 3v2) / profile.

Let's see if @Sakati84 can come up with something regarding this.

hfgd123, 2021-11-05:
Same problem here

Sakati84, 2021-11-10:
@MXZZ your GCode looks fine to me. I would guess your Z Axis misses a step because of high speed. Can you try printing with a lowered Z Axis speed?

dschaadt, 2022-03-28:
Look like a cool project, unfortuantely it's not working for me on an Ender 3 V2, even with z axis speed set to 5. Has this been resolved? Where can I add something that the z axis moves up for each printed layer?

MXZZ, 2022-06-25:
I commented this line in the python script
            '''lines = self.addExplicitZ(lines)'''
and it seems to work so far ( i'm trying a simple model) ,   please try and let me know, I'm using now a Voxelab Aquila x2 ( it had the same issue)

fnorbenden, 2023-02-07:
> I commented this line in the python script '''lines = self.addExplicitZ(lines)''' and it seems to work so far ( i'm trying a simple model) , please try and let me know, I'm using now a Voxelab Aquila x2 ( it had the same issue)

This also fixed an issue I had with height being added to layers and breaking the print. Not sure what that function does (I haven't had a chance to look at it) but it seems to just break things.

fnorbenden, 2023-02-15:
I took another look at the function itself and it's trying to use next() on a list (from re.findall) instead of an iterator. That is probably breaking the output and leading to unpredictable results messing with Z coordinates of G0 and G1 commands.

I also don't see any real reason to generate the list in the first place.

`coord = re.findall(r'[XYZF].?\d+(?:.\d+)?', line)
                Z = next((i for i in coord if i.startswith('Z')), None)`

and

`Z = re.findall(r'Z.?\d+', line)`

should return the exact same thing, the Z coordinate for a G0/G1 command, which is the only thing we care about. Without the typing issue.

I'll have to test it

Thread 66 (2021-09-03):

[Question / Feature Request] Drawing / Coloring on paper without hotend / heated bed

JMVS, 2021-09-03:
Great project! Just finished printing all the parts, installing, calibrating and doing a first test run on an Ender 3 v2. All seems to be working according to plan.

I would like to know if it is possible to use the system to just _draw_ on paper without using the hotend nor the heated bed. I assume is possible by just using a single layer model, not using Extruder 1 and turning off hotend & bed temperatures and setting the fans off. I'm not really sure about the Z-Offset and maybe a Z-Hop when travelling?

I would like to hear from your thoughts about this.

**Thanks again for this project!**

JMVS, 2021-09-04:
### Alright first test drive with the butterfly went OK:
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
_(don't mind the circles, they were the very first try)_
Took really loooong time (about an hour) because the Extruder 1 (hotend) did all the paths first at initial layer speed. Also forgot to turn on Z-Hop for all extruders.

### Second test went really well:
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
This took about 15 minutes as I manually deleted all the Extruder 1 (hotend) lines from G-Code. I've yet to figure out if this can be done automatically done by the post-processing plugin.

### Color setup:
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

### What I changed:
**Profile**:
- Disble all heating and cooling for all extruders (basically turning off or setting to zero)
- Enable Retraction on and set retraction distance to 0 for all extruders
- Enable Z-Hop and set distance to 5.0mm to all extruders
- Changed speed up
- Some other tweaks here and there (0% infill, spiralize outer countour, and some others)

**PenColorized Post-Processing Plugin**:
- Retraction during painting set to 0
- Disable Interlace colors

**G-Code**:
- Manually removed all Extruder 1 (hotend) related lines.

Test file (rename extension .gcode)
[CFFFP_Mariposa_rev2.txt](https://github.com/Sakati84/3DPrintColorizer/files/7110311/CFFFP_Mariposa_rev2.txt)
**_(NOT for printing your printer values might differ and cause problems)_**

Here's the Illustrator file I used:
[Butterfly test.zip](https://github.com/Sakati84/3DPrintColorizer/files/7110321/Butterfly.test.zip)

Sakati84, 2021-09-07:
Very cool! I think I will add a "Draw only"-mode to the plugin in the future!

JMVS, 2021-09-07:
What is very important is to make sure there's **no extruder movement**. In my tests I took out the filament just to be on the safe side, as moving the extruder (either way) with the hotend cold (and thus the filament) would be a bad idea.

Some other things I noticed for this to work perfectly:
- When changing pens, the pen goes to the last "printed" point and makes a dot. Then moves up and travels to the next point (where the new pen should start drawing)
- The profile should be tweaked so there's only one wall and the rest infill).
- Following this, I don't know how I messed up, but from one point forward I started having a lot of Z Hops on the same pen (maybe due to the thickness of the drawing the settings on the profile).
- Not much of a problem, and maybe it's to accomodate different printers, but there's too much Z travel when putting one pen and taking another. This could be set as a parament of the plugin so can be adjusted by the user.
- All extuder 1 movements should be removed from gcode
- All temps & fans should be at zero / off

I'm sending some other sample over cardboard (had to adjust Z-Offset):
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

I can help with testing if needed. Thanks again for a great work!

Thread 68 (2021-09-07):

Color offset from print

buddybu, 2021-09-07:
I am seeing an offset in both the x and y axis, but mostly x.  I did the calibration as described, is there something I am missing?
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
Ignore the bad print, I am working through clogging issues.  I am running on anet a8 hardware, but with an E3Dv6 clone hotend and Bowden extruder as well as an SKRv1.4

buddybu, 2021-09-07:
[configuration.zip](https://github.com/Sakati84/3DPrintColorizer/files/7118793/configuration.zip)

Sakati84, 2021-09-07:
Sorry but I don´t have any clue about this. The generated GCode for coloring isn´t diffrent from the other GCode generated by Cura so I don`t see anything special that could go on here. Perhaps you can manually look at the GCode and make sure it´s alright?

buddybu, 2021-09-08:
The solution is to add your X_MIN_POS/Y_MIN_POS or MANUAL_X_HOME_POS/MANUAL_Y_HOME_POS to the X and Y offset in the post processing dialog.  Be sure to use the absolute value, i.e., if your X_MIN_HOME_POS is -18.4, then add 18.4 to the X offset you discovered lining up against the screw, and do the same for the Y offset you discovered lining up against the screw.

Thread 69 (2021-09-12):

Suggestion: have script skip painting over the infill

christopherjamesmeyers, 2021-09-12:
I've noticed the script spends a lot of time painting over infill that wouldn't normally be seen and causes issues with layer adhesion (perhaps not letting the ink dry)

Sakati84, 2021-09-14:
Normally it should only paint the walls. Can you send me a photo of the infill painting?

christopherjamesmeyers, 2021-09-25:
Realized I was only looking at the first few layers before it started the infill. however, there is still the issue of layer adhesion

csanii123, 2021-09-25:
I didn't have any issues with my basic multi-color prints and layer adhesion. Do you have any issues when doing non-multi-color prints ? Perhaps you don't have your bed close enough and thus not enough "squish" between layers.

Sakati84, 2021-09-25:
What is your top/bottom  speed?

christopherjamesmeyers, 2021-09-26:
@csanii123 regular prints work just fine
@Sakati84 15 mm/s

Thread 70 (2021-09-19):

Printing pen rack

hfgd123, 2021-09-19:
I wanted to print the pen rack, but the first layer was only printed partwise and the next layers (until I canceled the print) the hotend scratched over the lower layers. Everything else I try to print works well. So I thought maybe anyone here could help me. Heres a picture of what was intended to be the pen rack (printed with an Ender-3) :
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

csanii123, 2021-09-19:
I haven't tried printing this model but it looks like your bed isn't level as the bottom right seems to have no brim/raft while the top does seem to have it intact. Suggest a relevel and use a skirt and see if that sticks well. If it does then move back to printing with a brim.

hfgd123, 2021-09-19:
The problem with that: I leveled the bed a few minutes before I started printing this. And the first time I tried printing the pen rack (also with leveling right before), there was the same problem. But I'll try printing with a skirt next weekend

csanii123, 2021-09-19:
Did you heat the bed/nozzle and then level ? When I 1st got my printer I wasn't doing that and prints were "ok" but the stick to the bed was hit and miss. Since I heated the bed/nozzle and then leveled...prints are much better and stick to the bed very well.

hfgd123, 2021-09-19:
Bed and nozzle are always heated when I am leveling, yes

hfgd123, 2021-09-26:
It worked now. thx

Closed 2021-09-26.

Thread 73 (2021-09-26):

Suggestion: Easy support removal with pens

bennizone, 2021-09-26:
Hello,

in the past, I've seen a video where someone paused the print, added some edding on the supportmaterial and resumed the print. The result was an easier removeable supportstructure. In this case the lower adheasion was an advantage. Perhaps you can optimize this behaviour?
Unfortunately I do not have an Ender - so perhaps I will modify your pen-mount for my Anet-A8 in the future.

Thanks for your great work and sharing it!

Sorry - bad english ;-)

Sakati84, 2021-09-26:
Checkout the support removal branch in the Github for this use case

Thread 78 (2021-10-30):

after slicing the model doesnt merge , but shows normal in slice sim. not gcode4.

howy123, 2021-10-30:
I followed all instructions and it does work BUT doesnt slice right. When i slice a multi color model in cura of coarse, it slices fine i can set any extruder i want and it slices the way it should but after i put the file on sd I saw the model was split up again in random places even tho I checked the slice in the sim and its fine. when i look at g-code its split up. why is this ? I see others on youtube using this mod and it works. It retrieves pen just fine , just does something to gcode wrong . Ive tried reinstalling cura 4.11.0 and same issue still.
any help please.......

Sakati84, 2021-11-02:
What you see in the preview are probably the gcode paths for the pens. Did you try printing the model?

howy123, 2021-11-02:
I played with the offsets and it looks good I haven't had time to test it
yet. It was doing a weird thing it would split my sliced model in to 2
parts. I am starting the settings on 0 and work my way to the correct
offset cause my measurements were prob not right. Thank you for the
reply.....

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

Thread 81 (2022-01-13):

Prusa MK3 skips G0 to move below pen

krisrok, 2022-01-13:
Skipping the move command results in the knocking the pens off the rack and not catching any pen at all.

Most likely it's because of missing space between the parameters in these lines:
```
G0 X62.0Z28.150000000000006 ;go under pen
```

Interestingly, this happens _only_ via USB, e.g when printing via Octoprint or sending the command via e.g. Octoprint's terminal.
Printing the exact same gcode from SD-card works as intended.

Closed 2022-01-21.

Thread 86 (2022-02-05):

Printer don't extrude

valle12345, 2022-02-05:
I need Help.
My Cr-10-V3 sets the Temperature at beginning to 150 and don't extrude. This behavior doesn't change in the whole print.
The Printer do the right movement.

This is the G-Code i'm using
[CFFFP_pikachu_dual_details.txt](https://github.com/Sakati84/3DPrintColorizer/files/8008574/CFFFP_pikachu_dual_details.txt)

fnorbenden, 2023-02-11:
`M104 S{ ; set final nozzle temp
M190 S{ ; wait for bed temp to stabilize
M109 S{ ; wait for nozzle temp to stabilize`

It looks like you're having issues passing a slicer (cura?) set variable to the script which results in a malformed command that the firmware ignores. Your gcode sets the hotend to 150 a few lines before that to prevent oozing while homing and since the only other hotend temp command is malformed, it never is set to a useful temperature.

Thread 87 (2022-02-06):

Cura is not slicing when the printer is supposed to grab a pen.

TheMeIonGod, 2022-02-06:
Cura says "The following script is active: PenColorizer" and I have all my offsets put into it. I manually made the profile based on what Cura profile files say (Cura kept crashing when trying to import it. If you know a fix for this problem too that would be nice). When choosing the model I put the 2 part 3DBenchy (So like the hull is one color and the rest is another). Assigning the hull to extruder 2 (To be black in this case) and rest to be white (Extruder 1). Also I checked to make sure that each part is from a different extruder which it was. But I noticed when putting the Gcode into a viewer it doesn't show it ever going up to grab the black sharpie. Trying another model it does the same thing even when running it never grabs the sharpie (Proving that the viewer is correct). How do I fix this?

Closed 2022-02-18.

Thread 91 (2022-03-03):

Not fetching marker

GoldenSnitch42, 2022-03-03:
I'm new to 3D printing so I apologize if I'm making a newbie mistake.  I'm using the stock firmware on my Ender 3 v2.  I've followed the instructions as closely as I could and I think I have everything setup correctly.

I did the Cura setup and sliced the multicolor parrot linked in the instructions after assigning the parts to the 4 extruders.

When I print I get the first layer or so down and the printing pauses for a few seconds without moving the head and then it continues to print.  If I let it go this happens several more times.  I've let it print a couple of millimeters but as it never attempted to pickup a marker I stopped it.  I'm assuming that at those pauses it's supposed to go get the marker and then do the coloring.

I've setup OctoPrint and have attempted the same print from it and I get many error messages all something like "Not queuing T0, that tool doesn't exist according to the printer profile or was reported as invalid by the firmware. Make sure your printer profile is set up correctly."  Sometimes its for T1 or T2 as well.

Should this work with the stock Creality firmware (1.0.2) or do I need to build and flash my own Marlin firmware?

Any other suggestions for getting this to work?

csanii123, 2022-03-03:
I was able to make this work on my stock Ender 3 v2 with firmware v1.0.2
You need to follow the software setup instructions as that inserts the
pen pickup/return commands.
https://github.com/Sakati84/3DPrintColorizer/wiki/4-Software-Setup

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

--
This email has been checked for viruses by Avast antivirus software.
https://www.avast.com/antivirus

csanii123, 2022-03-03:
I have not tried with Octoprint.
I copied the file direct to an SD card and used that.
In theory it should work the same for Octoprint as all it is doing is
sending the GCODE commands 1 line at a time the same the printer reading
from the SD card.

I should clarify I did not try printing the parrot but created my own
multi-color print for testing.

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

--
This email has been checked for viruses by Avast antivirus software.
https://www.avast.com/antivirus

GoldenSnitch42, 2022-03-06:
I got it to work, I redid all the software parts and everything is good to go the second time around.  Parrot printed pretty well.  I think my x axis offset might need tweaking.

Another question regarding the Ender 3 v2, the instructions say to set the Z axis speed to 100.  The max I can set it to is 10 from the default 5.  Is that the best I can do?

csanii123, 2022-03-06:
I honestly never played with the max z-speed as I wasn't sure if it
would cause issues with my printer.

With a non-stock firmware you might be able to adjust further but I am
sure Creality set a max for a reason.

I tried lowering the penholders and that was "ok" but still slow for
multi-color printing.

There was a limit on how low the pens could be since the pen swap
routine had to account for enough clearance to make the swap.

The other idea I was thinking about was a rotary pen holder so that the
pen swap didn't have to go to the top but rather would just go to the
far left or far right to swap pens.

I didn't actually build something for this as it would also require new
code for the amazing work that the current solution provides.

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

--
This email has been checked for viruses by Avast antivirus software.
https://www.avast.com/antivirus

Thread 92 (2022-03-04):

Suggestion: have a double sided holder for 12 markers

Nathan22211, 2022-03-04:
This should be doable on most gantry printers, as that's usually in the middle of the printer, but this will require calibration for the other side with a Y cord for both.

thisnyjared, 2024-01-08:
Unfortunately it's designed for ender 3's and wouldn't work on any bed slingers. You could though upload a remix of that onto the thingiverse page. https://www.thingiverse.com/thing:4918256

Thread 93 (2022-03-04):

Suggestion: Spacer bars that can be printed to raise the top bar.

Nathan22211, 2022-03-04:
This way the markers can be grabbed, but you can still print at their full height. Should fix issues with some direct drives as well

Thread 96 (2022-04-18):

The repo's wiki seems to use spaces and periods as it's only punctuation and has some spelling errors

Nathan22211, 2022-04-18:
I'm trying to fix it by writing a wiki myself but you can't PR those, unfortunately. You can clone it on my fork with this link: https://github.com/Nathan22211/3DPrintColorizer.wiki.git

Mind you I'm not done and my formatting isn't the best. My writing style is also a lot different from whoever wrote the current wiki.

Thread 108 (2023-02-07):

Flat Surfaces Between Virtual Extruders Do Not Bond

fnorbenden, 2023-02-07:
Since the plugin paints the exterior 2 walls of every surface, a flat surface shared by two colorized objects will not adhere properly and the print will either be unstable or fall apart.

Expected behavior: 3 stacked colored cubes will have a continuous infill from the base to the top layer
Current behavior: the printer will print 3 discrete colored cubes stacked on top of each other, with infill broken by 4 colorized layers between each cube.

As with the last issue, I understand that this project is defunct, so I am opening this issue in the hopes that I or someone else can figure out an elegant solution and use this issue to link a relevant pull request.

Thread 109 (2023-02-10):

Stops printing

ElijahSpirit, 2023-02-10:
After printing the first layer the extruder temperature suddenly drops to 0. it nevers moves up or anything. just keeps printing like nothinbgs happened but isnt moving extruder gear and sets the temperature to zero

ElijahSpirit, 2023-02-11:
It is a direct drive ender 3.

fnorbenden, 2023-02-11:
The script should never change the hotend temperature; the only time it touches M104 is specifically to remove them to avoid firmware issues with a cold "extruder" that's been changed to a pen.

Have you tried slicing/printing this model without the script (remember to screenshot the settings if you remove it because it is dumb about keeping them)? Could you pastebin your gcode for each? Are you using marlin or klipper?

ElijahSpirit, 2023-02-11:
Hi! The issue occurs when using octoprint with an error tracking default plugin.

Closed 2023-02-11.

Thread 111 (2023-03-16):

plugin not loading in Cura

scanlight, 2023-03-16:
Hi all having some issues with loading the plugin to cura.

Copied the py script to the plugin folder stated in the instruction and restarted Cura. still the plugin doesnt show up in the plugin list.
Tried cura 2.4, 4.9.0, 4.9.1 5.2 and 5.3

Is this script version specific or some other issue ?
What version is best used?

Hope somebody can point me in the right direction after printing all the parts haha. 👍

LouisLe18, 2023-03-17:
I used 4.9.0 and it loaded. But I'm still trying to get it to print properly

scanlight, 2023-03-17:
checking the logs it has an issue with the title starting with a decimal. changed this and tried again.
now issue at line 8
<!DOCTYPE html>
  ^
 SyntaxError: invalid syntax

scanlight, 2023-03-17:
full Log part with error:

2023-03-17 19:27:53,229 - ERROR - [MainThread] PostProcessingPlugin.PostProcessingPlugin.loadScripts [221]: Exception: Exception occurred while loading post processing plugin: invalid syntax (PenColorizer.py, line 8)
2023-03-17 19:27:53,229 - ERROR - [MainThread] PostProcessingPlugin.PostProcessingPlugin.loadScripts [221]: Traceback (most recent call last):
2023-03-17 19:27:53,230 - ERROR - [MainThread] PostProcessingPlugin.PostProcessingPlugin.loadScripts [221]:   File "C:\Program Files\UltiMaker Cura 5.3.0\share\cura\plugins\PostProcessingPlugin\PostProcessingPlugin.py", line 201, in loadScripts
2023-03-17 19:27:53,230 - ERROR - [MainThread] PostProcessingPlugin.PostProcessingPlugin.loadScripts [221]:     spec.loader.exec_module(loaded_script)  # type: ignore
2023-03-17 19:27:53,230 - ERROR - [MainThread] PostProcessingPlugin.PostProcessingPlugin.loadScripts [221]:   File "<frozen importlib._bootstrap_external>", line 879, in exec_module
2023-03-17 19:27:53,231 - ERROR - [MainThread] PostProcessingPlugin.PostProcessingPlugin.loadScripts [221]:   File "<frozen importlib._bootstrap_external>", line 1017, in get_code
2023-03-17 19:27:53,231 - ERROR - [MainThread] PostProcessingPlugin.PostProcessingPlugin.loadScripts [221]:   File "<frozen importlib._bootstrap_external>", line 947, in source_to_code
2023-03-17 19:27:53,231 - ERROR - [MainThread] PostProcessingPlugin.PostProcessingPlugin.loadScripts [221]:   File "<frozen importlib._bootstrap>", line 241, in _call_with_frames_removed
2023-03-17 19:27:53,232 - ERROR - [MainThread] PostProcessingPlugin.PostProcessingPlugin.loadScripts [221]:   File "C:\Users\robbert\AppData\Roaming\cura\5.3\scripts\PenColorizer.py", line 8
2023-03-17 19:27:53,232 - ERROR - [MainThread] PostProcessingPlugin.PostProcessingPlugin.loadScripts [221]:     <!DOCTYPE html>
2023-03-17 19:27:53,232 - ERROR - [MainThread] PostProcessingPlugin.PostProcessingPlugin.loadScripts [221]:     ^
2023-03-17 19:27:53,233 - ERROR - [MainThread] PostProcessingPlugin.PostProcessingPlugin.loadScripts [221]: SyntaxError: invalid syntax
2023-03-17 19:27:53,234 - ERROR - [MainThread] PostProcessingPlugin.PostProcessingPlugin.loadScripts [221]: Exception: Exception occurred while loading post processing plugin: invalid syntax (PenColorizer.py, line 8)
2023-03-17 19:27:53,235 - ERROR - [MainThread] PostProcessingPlugin.PostProcessingPlugin.loadScripts [221]: Traceback (most recent call last):
2023-03-17 19:27:53,235 - ERROR - [MainThread] PostProcessingPlugin.PostProcessingPlugin.loadScripts [221]:   File "C:\Program Files\UltiMaker Cura 5.3.0\share\cura\plugins\PostProcessingPlugin\PostProcessingPlugin.py", line 201, in loadScripts
2023-03-17 19:27:53,235 - ERROR - [MainThread] PostProcessingPlugin.PostProcessingPlugin.loadScripts [221]:     spec.loader.exec_module(loaded_script)  # type: ignore
2023-03-17 19:27:53,236 - ERROR - [MainThread] PostProcessingPlugin.PostProcessingPlugin.loadScripts [221]:   File "<frozen importlib._bootstrap_external>", line 879, in exec_module
2023-03-17 19:27:53,236 - ERROR - [MainThread] PostProcessingPlugin.PostProcessingPlugin.loadScripts [221]:   File "<frozen importlib._bootstrap_external>", line 1017, in get_code
2023-03-17 19:27:53,236 - ERROR - [MainThread] PostProcessingPlugin.PostProcessingPlugin.loadScripts [221]:   File "<frozen importlib._bootstrap_external>", line 947, in source_to_code
2023-03-17 19:27:53,237 - ERROR - [MainThread] PostProcessingPlugin.PostProcessingPlugin.loadScripts [221]:   File "<frozen importlib._bootstrap>", line 241, in _call_with_frames_removed
2023-03-17 19:27:53,237 - ERROR - [MainThread] PostProcessingPlugin.PostProcessingPlugin.loadScripts [221]:   File "C:\Users\robbert\AppData\Roaming\cura\5.3\scripts\PenColorizer.py", line 8
2023-03-17 19:27:53,237 - ERROR - [MainThread] PostProcessingPlugin.PostProcessingPlugin.loadScripts [221]:     <!DOCTYPE html>
2023-03-17 19:27:53,238 - ERROR - [MainThread] PostProcessingPlugin.PostProcessingPlugin.loadScripts [221]:     ^
2023-03-17 19:27:53,238 - ERROR - [MainThread] PostProcessingPlugin.PostProcessingPlugin.loadScripts [221]: SyntaxError: invalid syntax

scanlight, 2023-03-17:
solved! thnks

Closed 2023-03-17.

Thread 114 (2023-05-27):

Calibration for Ender 3 V2 Neo

ScowlingZebra, 2023-05-27:
Hi, when following the instructions I encountered a problem with getting the pen part, when i start using the prepare -> move command, the printer automatically starts homing the nozzle. there a way to get around this?

doggohusk, 2023-08-28:
had the same issue with my ender 3 max neo which also auto homes the nozzle i still wrote down the cords just in case and as expected it drew the pen 100 mm away from the print into the corner i got lucky with tuning off set tho my printers pen offsets are X=37 Y=44 Z=2.7 this might help?

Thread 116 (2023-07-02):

Idea for corexy

noobyme, 2023-07-02:
Can simply bolt a frame to the bed extrusions and hang the same way as regular or, using springs or rubber bands, have x axis rail hit a lever bringing down the rack at which point the hotend carriage holds the pen then can move to the side a little bit and unslotting then pen. U probably already thought of this

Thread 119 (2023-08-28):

X Y Pen offset constantly changes by .5 MM after each print

doggohusk, 2023-08-28:
was doing some general testing with the colorizer and tuned in x y and z pen offset perfectly how ever the next prints x and y offsets changed by about .5 mm and would sometimes change back on the next print or go off by about another .5 mm, i did calibration correctly and didnt do any changes to slicing settings other than increase layer height to .2mm.

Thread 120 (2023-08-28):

[Suggestion] Compatibility with newer models in ender 3 line up

doggohusk, 2023-08-28:
printed everything in hardware folder for my ender 3 max neo which i think released earlier this year and noticed the penrack doesnt go low enough for the print head to put the marker back up even putting the rack on the bottom part of the top bar on my printer it was still too high managed to find an stl that would get let it go low enough to (hopefully) let it put the marker back up on the rack, still printing as off right now but would be helpful if there were available compatable pen racks for later ender 3 series printers so as to not waste filament.

doggohusk, 2023-08-28:
finished printing today in the morning just installed couple of hours ago rack is low enough now so it works great

thisnyjared, 2024-01-07:
It is compatible with any bl touch compatible printer except for corexyz is that what you mean?

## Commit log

2021-07-19 Added STLs and Images for Doc
    [PenCap.stl, PenHolderArm.stl, PenHolder_Amazon_ShuttleArt(_Sharpie).stl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]
2021-08-01 Added several Mounting Options for Ender 3v2 and BLTouch
    [PenHolderArm_Ender3v1.stl, PenHolderArm_Ender3v2_byMolesza.stl, PenHolder_BLTouch_horizontalByZippitybamba.stl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]
2021-08-08 Integrated a BLToucvh Holder to the Pen Holder Arm
    [PenHolderArm_Ender3v1_IntegratedBLTouch.stl]
2021-08-11 Fixed retraction settings in CuraProfile and added 2 more extruders
2021-09-01 Add designs for Prusa i3 MK3S+ mount
    [Colorizer MK3S holder.stl, colorizer-extender.stl, colorizer-extruder-attachment.stl]
2021-09-18 Added new Pen Holder from Cyrus Sanii
    [PenHolder Ender3v2_Cyrus_Sanii (ClipOn).stl]
2023-02-07 Added hardware for Ultra-Fine Point Sharpies
    UF Sharpies take an order of magnitude longer to dry out and have a similar contact area for anything printed on .4mm or lower.
    [UFSharpieCap.3mf, UFSharpieHolderLong-2.3mf]
